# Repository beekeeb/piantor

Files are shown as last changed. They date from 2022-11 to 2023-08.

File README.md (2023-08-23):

# Piantor Keyboard

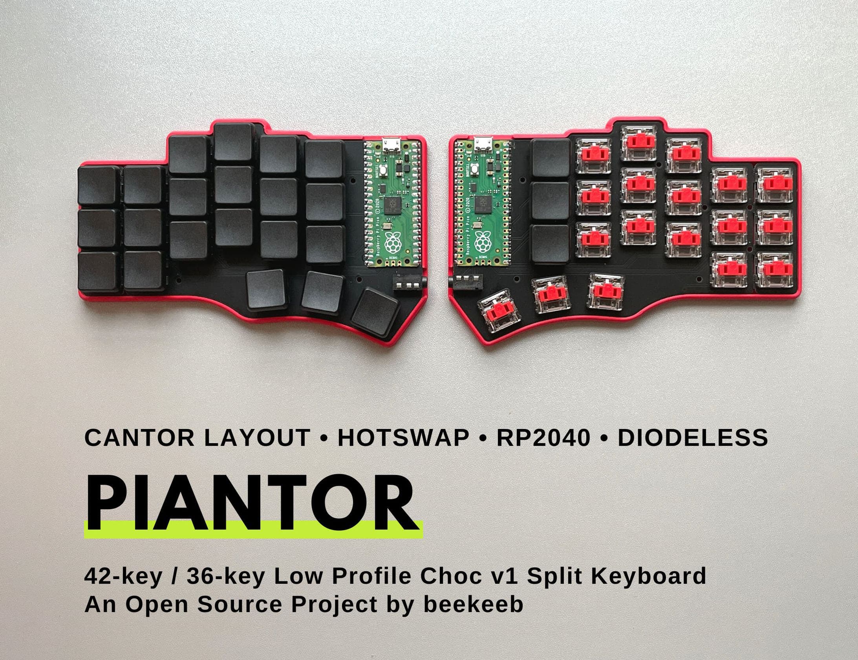
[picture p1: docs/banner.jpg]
Piantor Keyboard




The Piantor Keyboard is a 42-key or 36-key wired, diodeless, non-flippable, low profile choc v1 (hybrid hotswap and non-hotswap/soldered-in), aggressive column staggered, programmable ergonomic mechnical split keyboard powered by Rasyberry Pi Pico or other compatible RP2040 boards. It is based on the [Cantor Keyboard](https://github.com/diepala/cantor). The name "Piantor" is the portmanteau of "Pico" and "Cantor".

The development of this project is sponsored by [PCBWay](https://pcbway.com/g/beekeeb) (affiliate link).

## Quick Links

* [Build guide](https://docs.beekeeb.com/piantor-keyboard#build-guide)
* [Precompiled firmware](https://docs.beekeeb.com/piantor-keyboard#precompiled-firmware)
* [beekeeb showcase](https://showcase.beekeeb.com/piantor-keyboard/)

## Features

* RP2040 MCU - A low-cost, easy-to-source, powerful microcontroller with dual Arm Cortex-M0+ @ 133MHz, 264kB on-chip SRAM and 2MB (up to 16MB, depending on the breakout board) off-chip external flash memory. You can enable a lot of features and layers. Never worry about the firmware size limit.
* Cantor layout - Ergonomic strong column staggering for short pinkies.
* Non-flippable PCBs - Fewer ways to make mistakes when you install the controller breakout boards. Great for first time keyboard builders.
* Diodeless - A more robust build with fewer things to solder or break.
* Hybrid hotswap and soldered-in low profile choc switches - Experiment with different key switches with the hotswap sockets, or solder the key switches for a more stable build.
* Breakable pinky column - Easily convert the PCB from a 42-key to 36-key layout. You can snap off the pinky column without specialized tools.

## Bill of Materials (BOM)

Quantity | Item | Notes
--- | --- | ---
1 | Piantor PCB (Left)
1 | Piantor PCB (Right)
2 | RP2040 breakout boards (such as Raspberry Pi Pico or WeAct RP2040)
42 (or 36) | Kailh choc v1 PG1350 switches
42 (or 36) | "choc spacing" choc v1 keycaps
2 | TRRS jack (PJ-320A)
1 | 3.5mm TRRS cable | TRS cable cannot be used
42 (or 36) | CPG135001S30 hotswap sockets for choc v1 PG1350 | Optional, you can solder the switches directly if you do not use hotswap sockets
4 | Pin headers (20p) or sockets  | Only required for boards without castellated holes
2 | 10kΩ 1206 (3216M) SMD resistor | Only required if you do not want to use SPLIT_USB DETECT, and for boards without a built in VBUS_SENSE circuit
2 | 5.6kΩ 1206 (3216M) SMD resistor | Only required if you do not want to use SPLIT_USB DETECT, and for boards without a built in VBUS_SENSE circuit

* Note: Raspberry Pi Pico comes with castellated holes and a built in VBUS_SENSE circuit

## Ordering Parts

[DIY kits](https://shop.beekeeb.com/product/piantor-keyboard-kit/) and [prebuilt keyboards](https://shop.beekeeb.com/product/pre-soldered-piantor-split-keyboard/) are available at https://beekeeb.shop

If you prefer getting the parts by yourself, you can order the [Left Side PCB](https://www.pcbway.com/project/shareproject/Piantor_Keyboard_Left_side_24a2937f.html) and the [Right Side PCB](https://www.pcbway.com/project/shareproject/Piantor_Keyboard_Right_side_7c5b31eb.html).

A single side should cost around $31 for 5 pcs excluding shipping. For both sides, it should be around $62 in total for 5 sets.

## Firmware Status

* [QMK](https://github.com/qmk/qmk_firmware) - supported
* [Vial](https://github.com/beekeeb/vial-qmk-piantor) (based on QMK) - supported
* KMK (Python/CircuitPython) - pull request at https://github.com/KMKfw/kmk_firmware/pull/723
* [An example of KMK with miryoku](https://github.com/hansamann/piantor_miryoku_mac) by [hansamann](https://github.com/hansamann)
* Remap - support planned (No ETA)
* PRK (Ruby) - support planned (No ETA)
* keyberon (Rust) - support planned (No ETA)
* ZMK - waiting for [wired split support](https://github.com/zmkfirmware/zmk/issues/1110)

Precompiled firmware can be found at https://docs.beekeeb.com/piantor-keyboard.

## Cases

* [Piantor Gasket Mount Case by chewiedies](https://www.printables.com/model/536044-piantor-gasket-mount-case)
* [Piantor 36-key case with Tenting & Magnets! by Daave](https://www.printables.com/model/381730-piantor-36-key-case-with-tenting-magnets)
* [Travel case for Piantor keyboards by Rilton](https://www.printables.com/model/558902-travel-case-for-piantor-keyboards)

### Piantor Case with a Switch Plate (3D Printable)

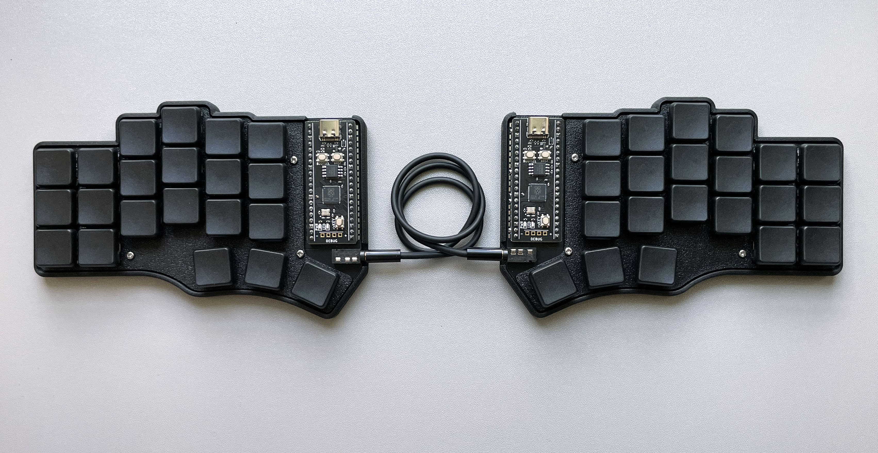
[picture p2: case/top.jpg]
Piantor Keyboard Case


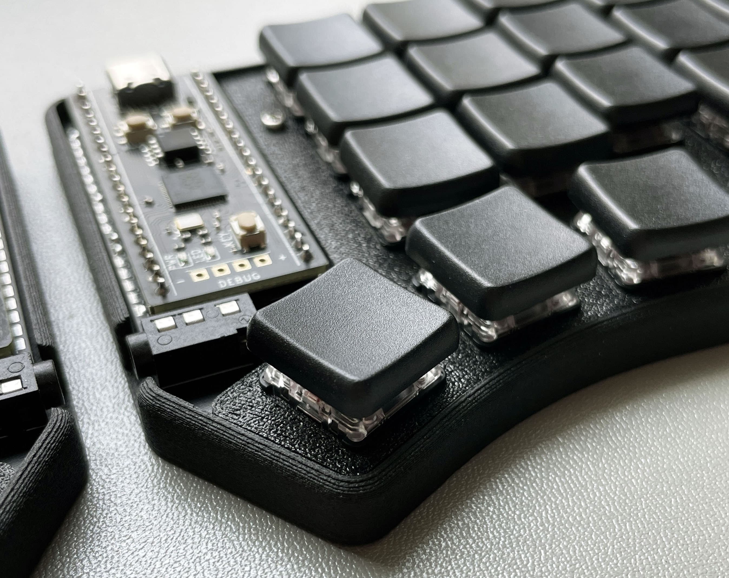
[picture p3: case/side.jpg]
Piantor Keyboard Case


The 3D printable case can be founded in the [case folder](./case). The switch plate is optional for the non-hotswap version.

GB823 M2 stainless steel screws with small pan heads are recommended.

* Screw Length
  * No switch plates: 4mm
  * With Switch plates: 6mm
  * With Switch plates and [Donut0804](https://shop.beekeeb.com/product/donut-silicone-rubber-feet-and-pads-o-rings-washers-like/)/o-rings: 7mm

Do not over-tighten the screws.

### Cantor Tray Case

The [Cantor Tray Case](https://www.thingiverse.com/thing:5382705) by chewiedies can be used. There is not a switch plate so it is not recommended for the hotswap version.

## Boards Preview

<p>
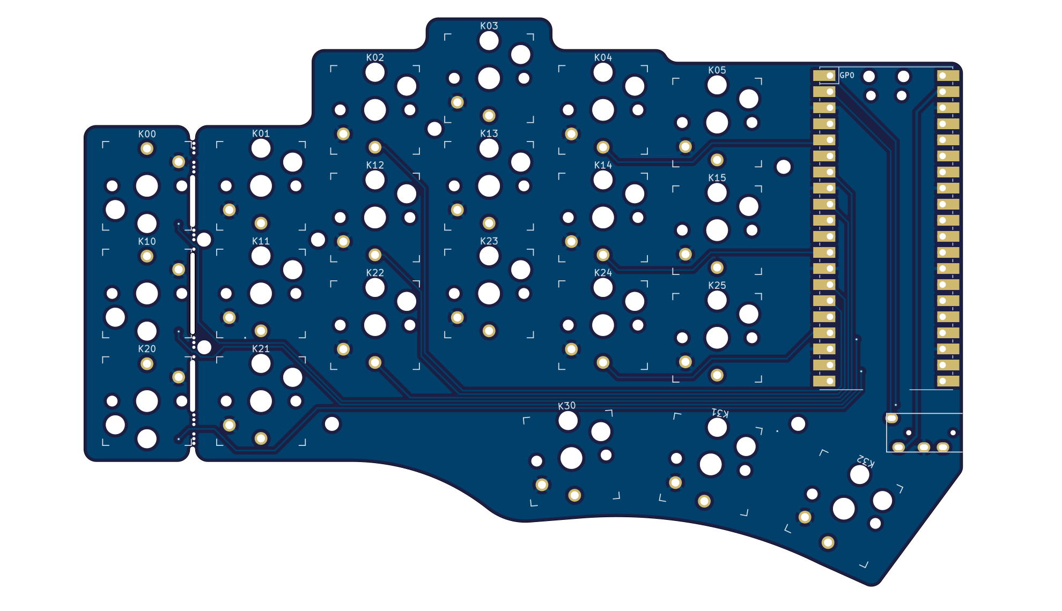
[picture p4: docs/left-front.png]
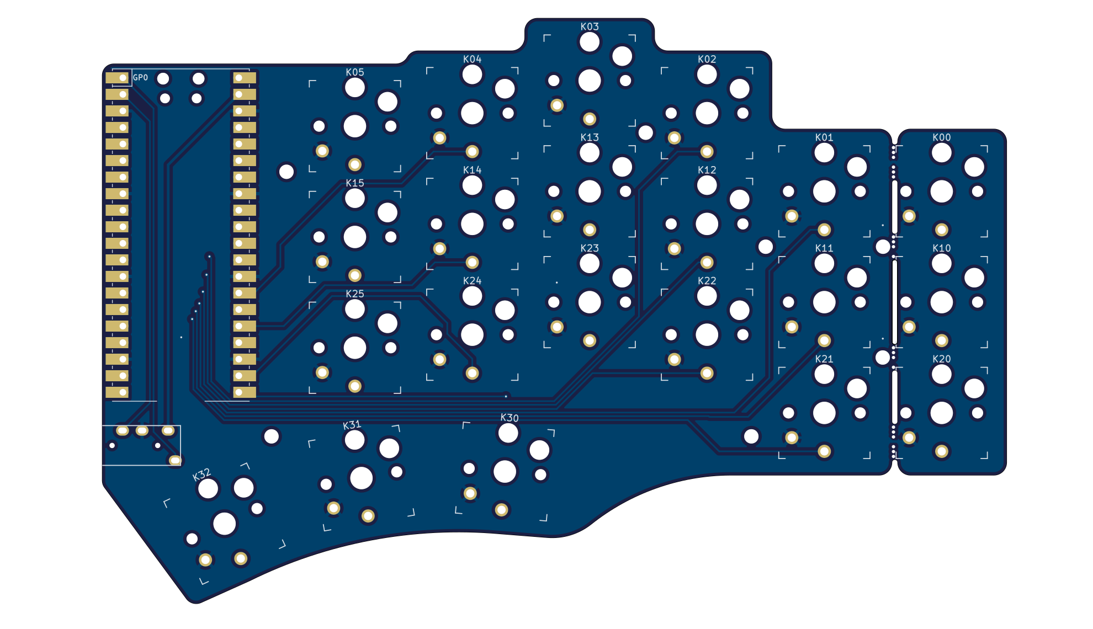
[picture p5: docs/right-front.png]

</p>
<p>
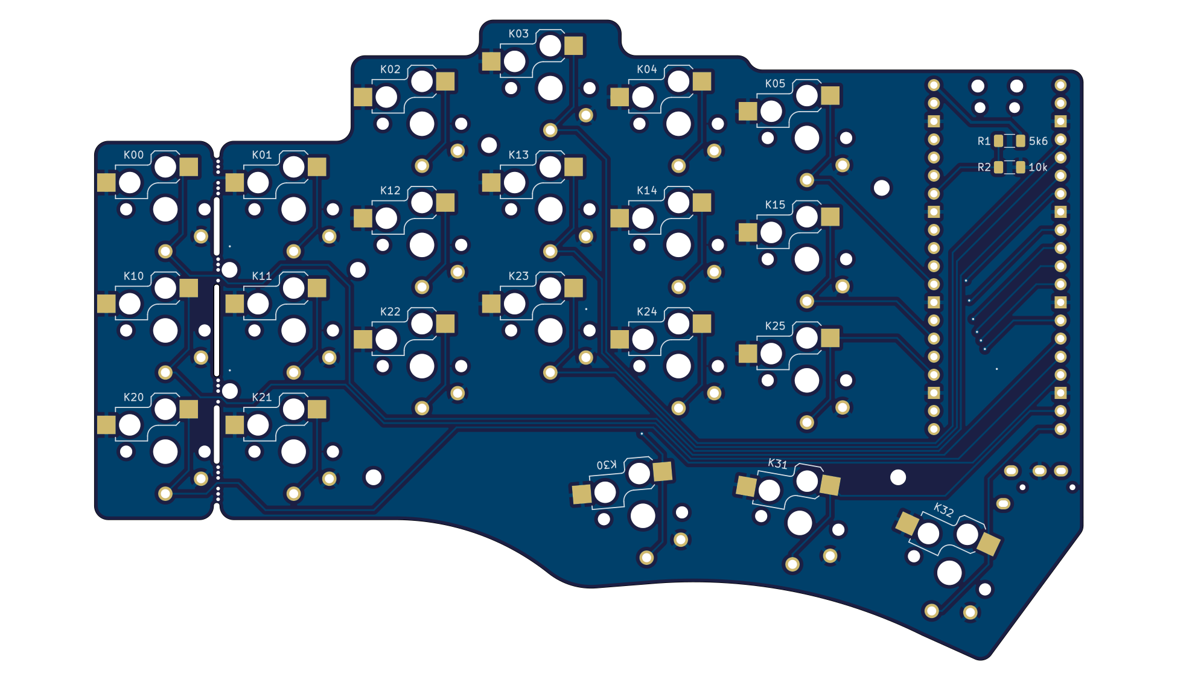
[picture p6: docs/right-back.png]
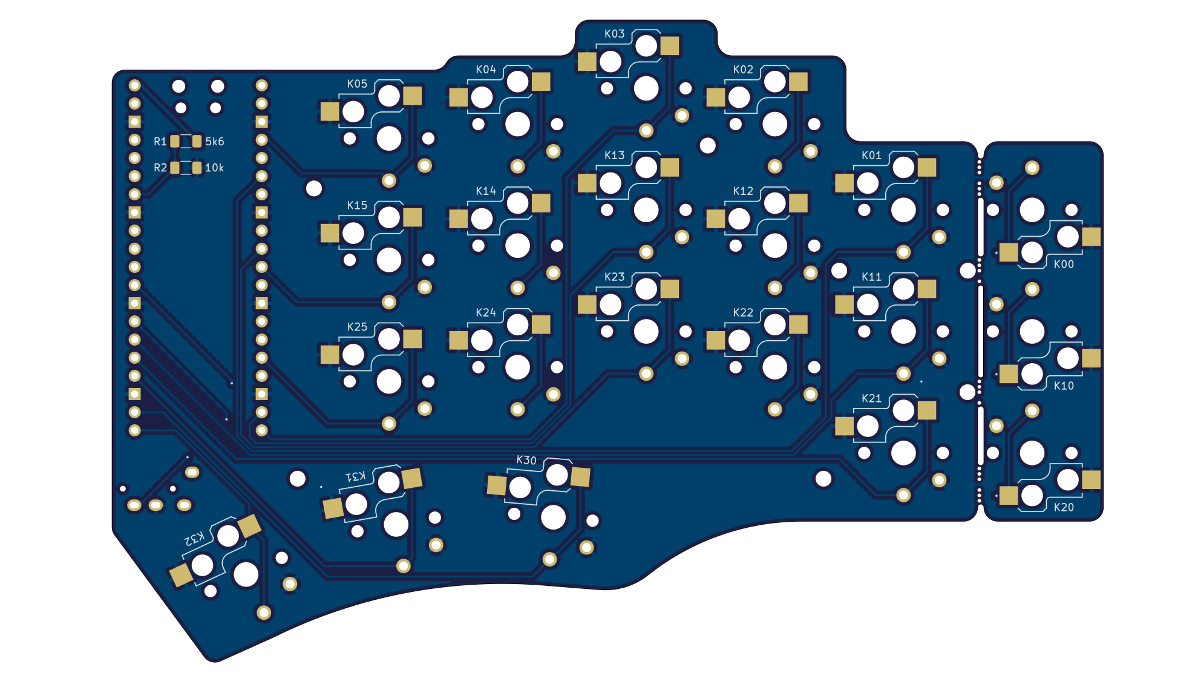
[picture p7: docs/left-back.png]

</p>

## License

External symbols and footprints are not covered by the LICENSE in this repo.

* [Keebio-Parts.pretty](https://github.com/keebio/Keebio-Parts.pretty) is licensed under the MIT License.
* [keyswitches.pretty](https://github.com/daprice/keyswitches.pretty) is licensed under the Creative Commons Attribution-ShareAlike 4.0 International License.
* [KiCad-RP-Pico](https://github.com/ncarandini/KiCad-RP-Pico) is licensed under the TPCWare KiCad Library License.
## Sponsors

This open source hardware project is sponsored by

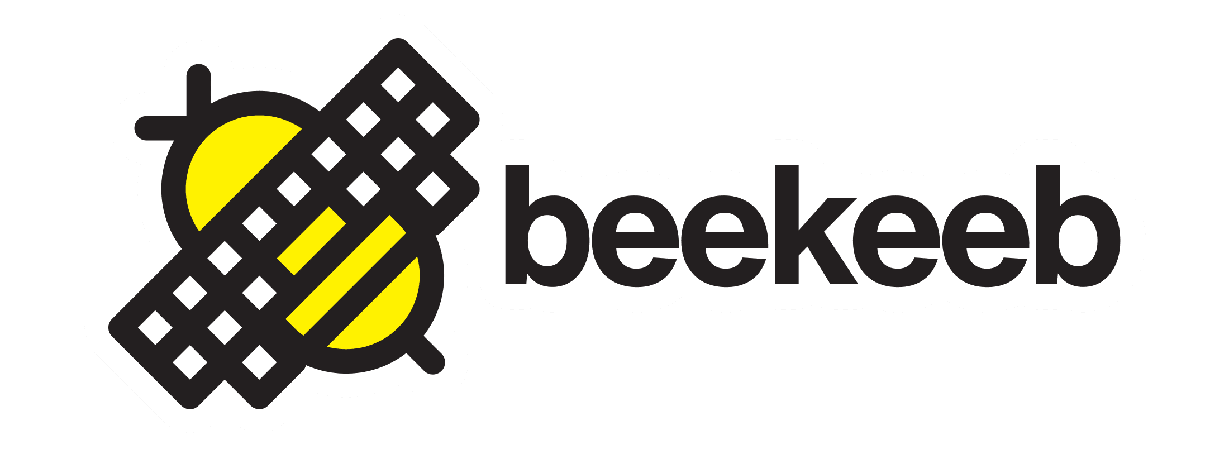
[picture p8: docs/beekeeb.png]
[](https://beekeeb.shop)
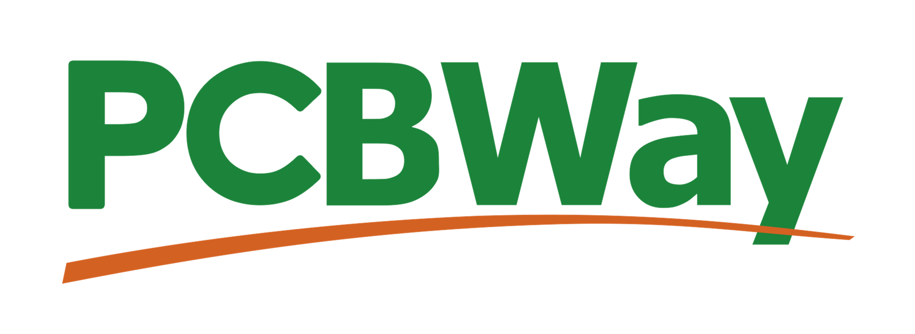
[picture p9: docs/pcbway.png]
[](https://pcbway.com/g/beekeeb)

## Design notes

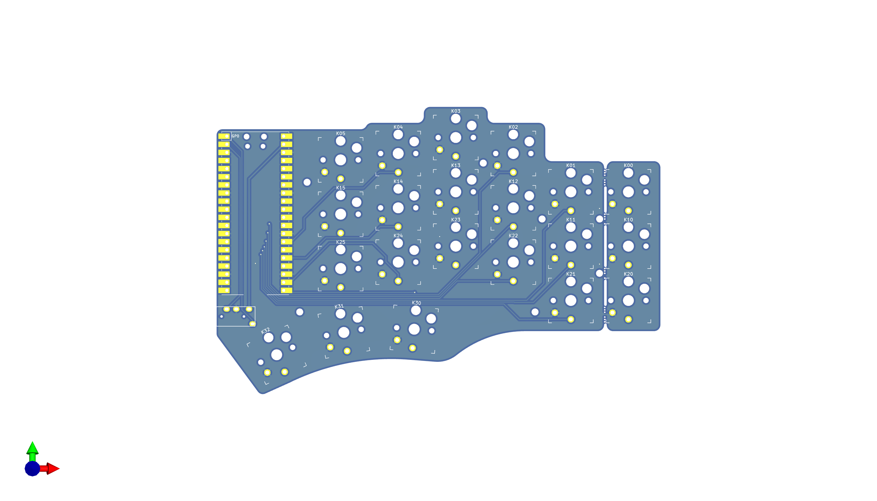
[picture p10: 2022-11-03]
docs/keyboard_right.png

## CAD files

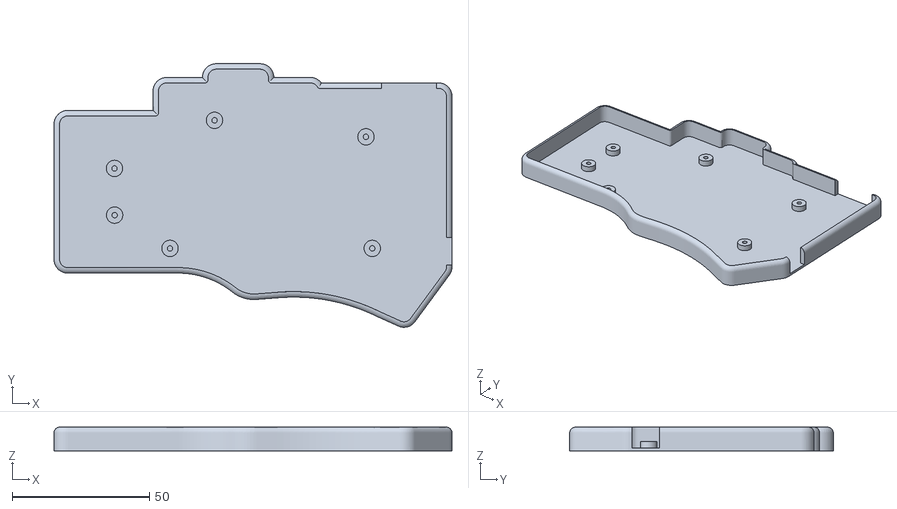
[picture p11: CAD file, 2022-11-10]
case/bottom.stl
144.8 x 95.9 x 8.60

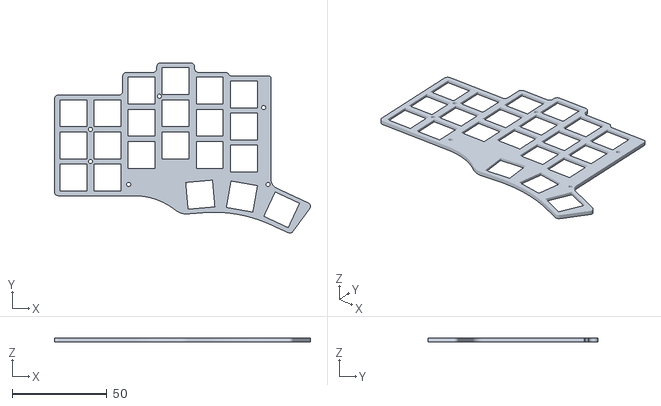
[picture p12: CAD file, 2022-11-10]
case/switch-plate.stl
135.2 x 89.9 x 2.00

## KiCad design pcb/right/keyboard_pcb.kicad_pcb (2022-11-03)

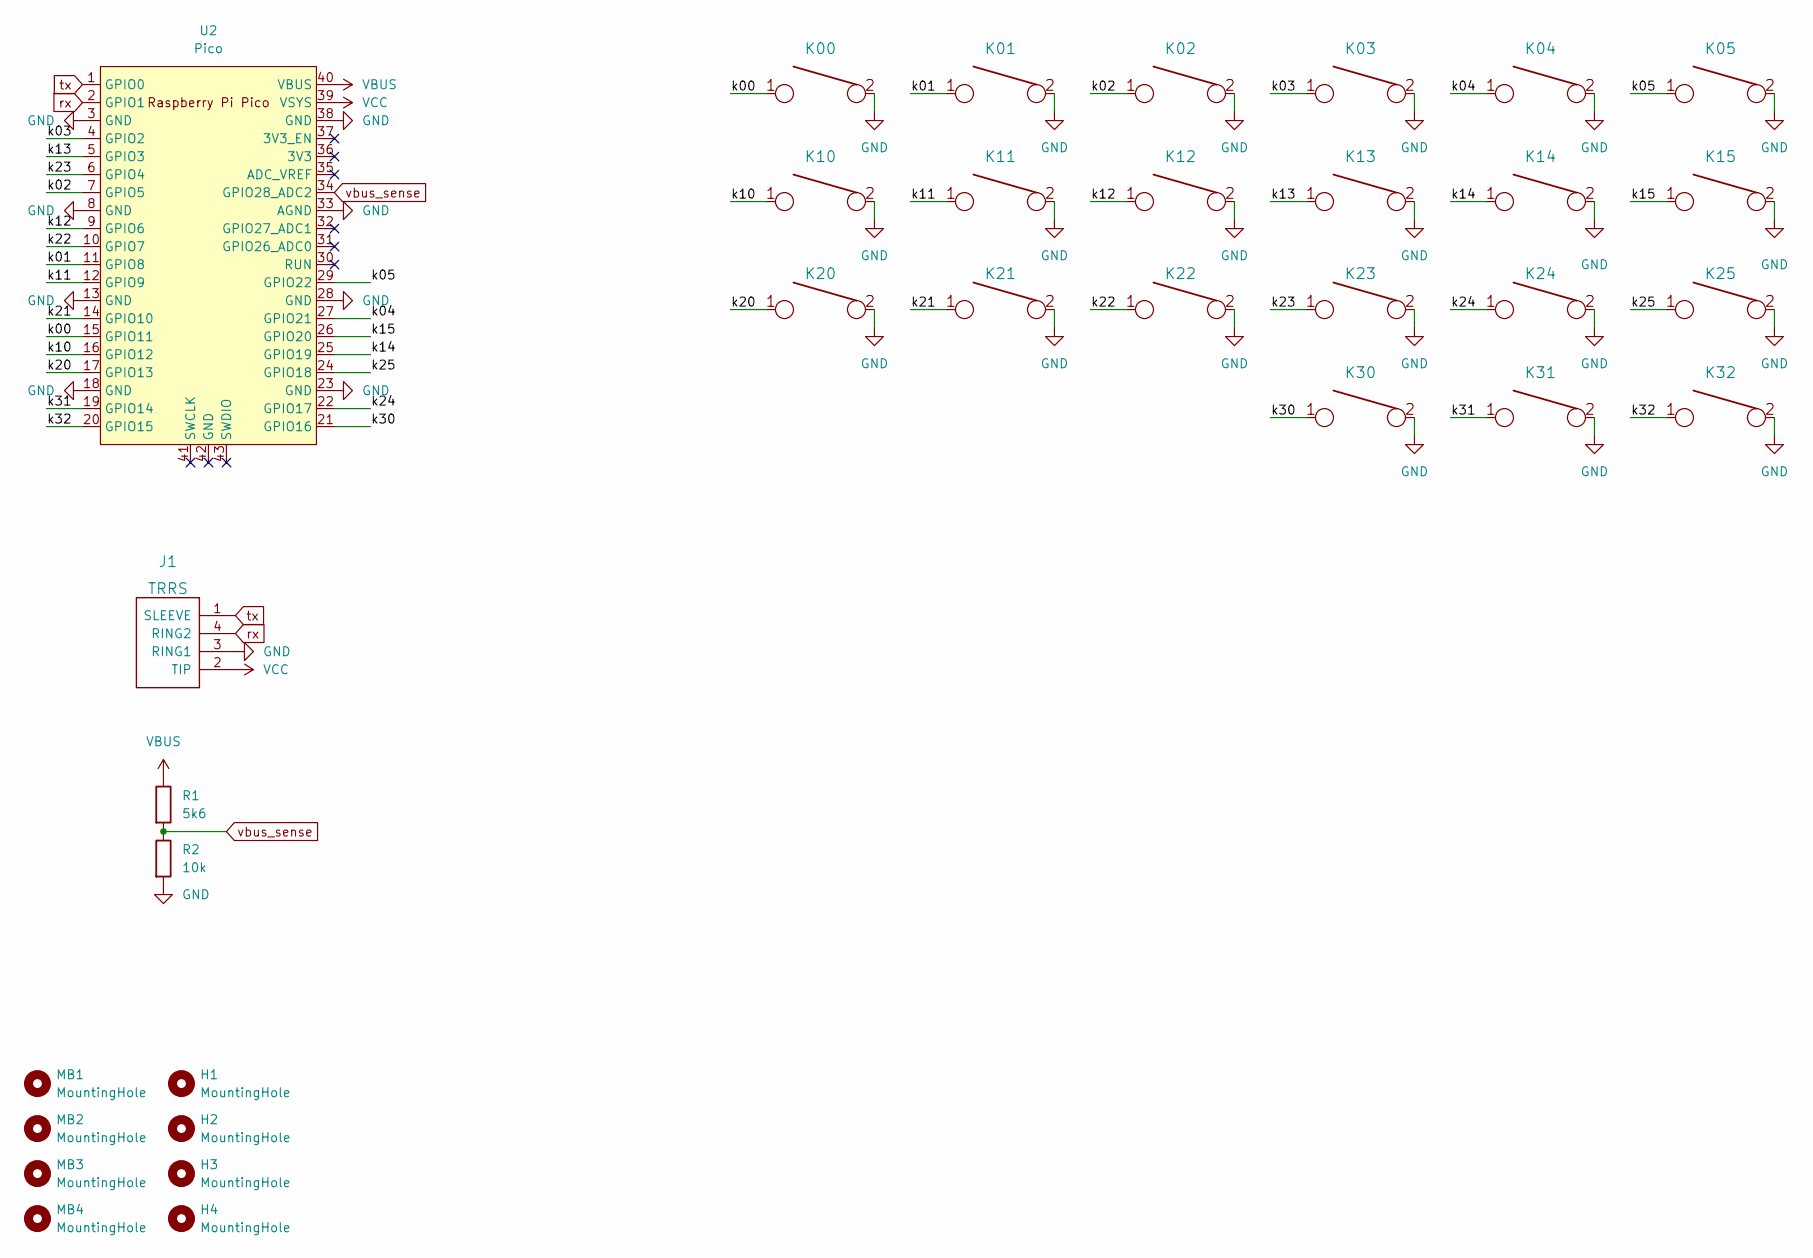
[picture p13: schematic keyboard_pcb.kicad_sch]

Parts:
H1, H2, H3, H4: MountingHole; MountingHole_2.2mm_M2-8mm
J1: TRRS; R_1206_3216Metric_Pad1.30x1.75mm_HandSolder
K00, K01, K02, K03, K04, K05, K10, K11, K12, K13, K14, K15, K20, K21, K22, K23, K24, K25, K30, K31, K32: KEYSW; SW_PG1350_reversible
MB1, MB2, MB3, MB4: MountingHole; mousebites
R1: 5k6; R_1206_3216Metric_Pad1.30x1.75mm_HandSolder
R2: 10k; R_1206_3216Metric_Pad1.30x1.75mm_HandSolder
U2: Pico; RPi_Pico_SMD_TH

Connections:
/k00: K00.1, U2.15 (GPIO11)
/k01: K01.1, U2.11 (GPIO8)
/k02: K02.1, U2.7 (GPIO5)
/k03: K03.1, U2.4 (GPIO2)
/k04: K04.1, U2.27 (GPIO21)
/k05: K05.1, U2.29 (GPIO22)
/k10: K10.1, U2.16 (GPIO12)
/k11: K11.1, U2.12 (GPIO9)
/k12: K12.1, U2.9 (GPIO6)
/k13: K13.1, U2.5 (GPIO3)
/k14: K14.1, U2.25 (GPIO19)
/k15: K15.1, U2.26 (GPIO20)
/k20: K20.1, U2.17 (GPIO13)
/k21: K21.1, U2.14 (GPIO10)
/k22: K22.1, U2.10 (GPIO7)
/k23: K23.1, U2.6 (GPIO4)
/k24: K24.1, U2.22 (GPIO17)
/k25: K25.1, U2.24 (GPIO18)
/k30: K30.1, U2.21 (GPIO16)
/k31: K31.1, U2.19 (GPIO14)
/k32: K32.1, U2.20 (GPIO15)
GND: J1.3 (RING1), K00.2, K01.2, K02.2, K03.2, K04.2, K05.2, K10.2, K11.2, K12.2, K13.2, K14.2, K15.2, K20.2, K21.2, K22.2, K23.2, K24.2, K25.2, K30.2, K31.2, K32.2, R2.2, U2.3 (GND), U2.8 (GND), U2.13 (GND), U2.18 (GND), U2.23 (GND), U2.28 (GND), U2.33 (AGND), U2.38 (GND)
VBUS: R1.1, U2.40 (VBUS)
VCC: J1.2 (TIP), U2.39 (VSYS)
rx: J1.4 (RING2), U2.2 (GPIO1)
tx: J1.1 (SLEEVE), U2.1 (GPIO0)
vbus_sense: R1.2, R2.1, U2.34 (GPIO28_ADC2)

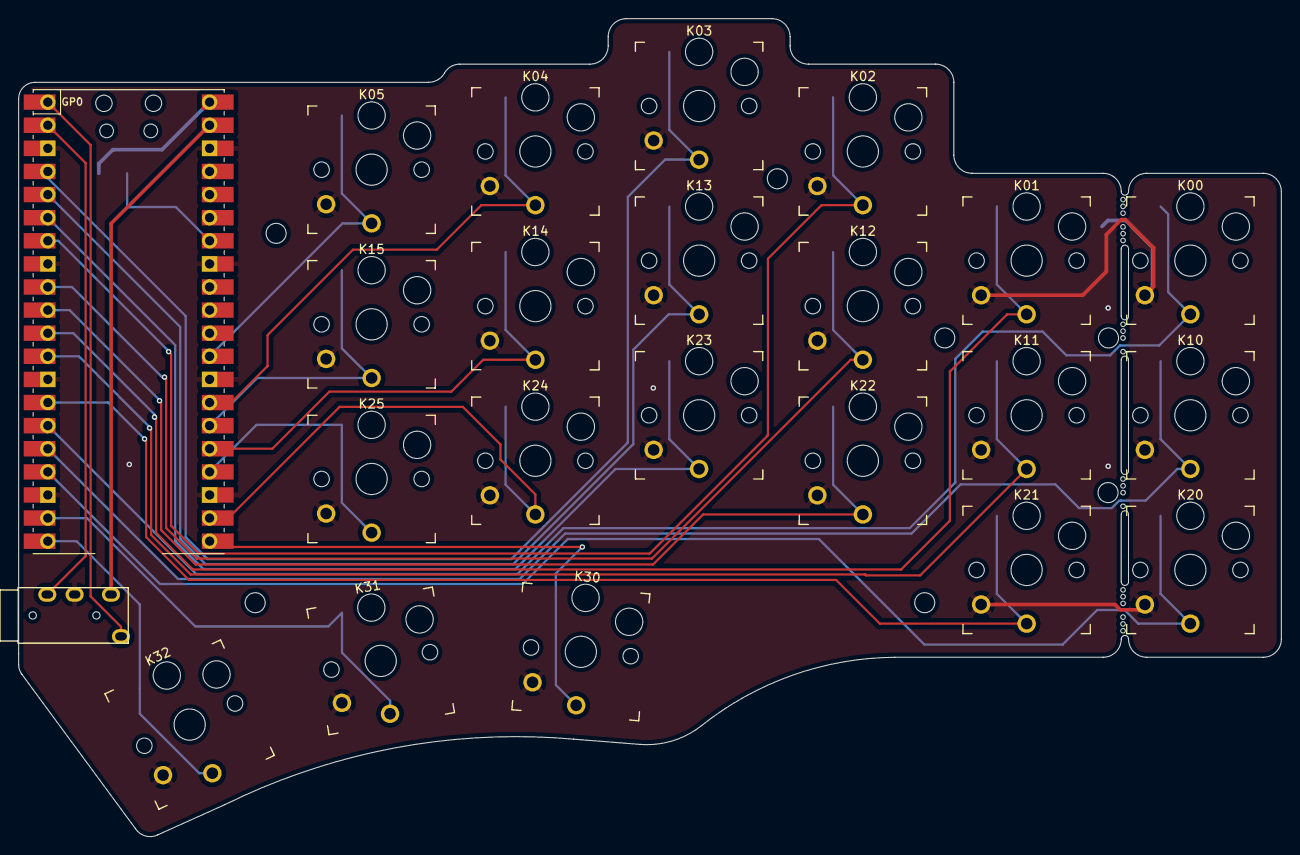
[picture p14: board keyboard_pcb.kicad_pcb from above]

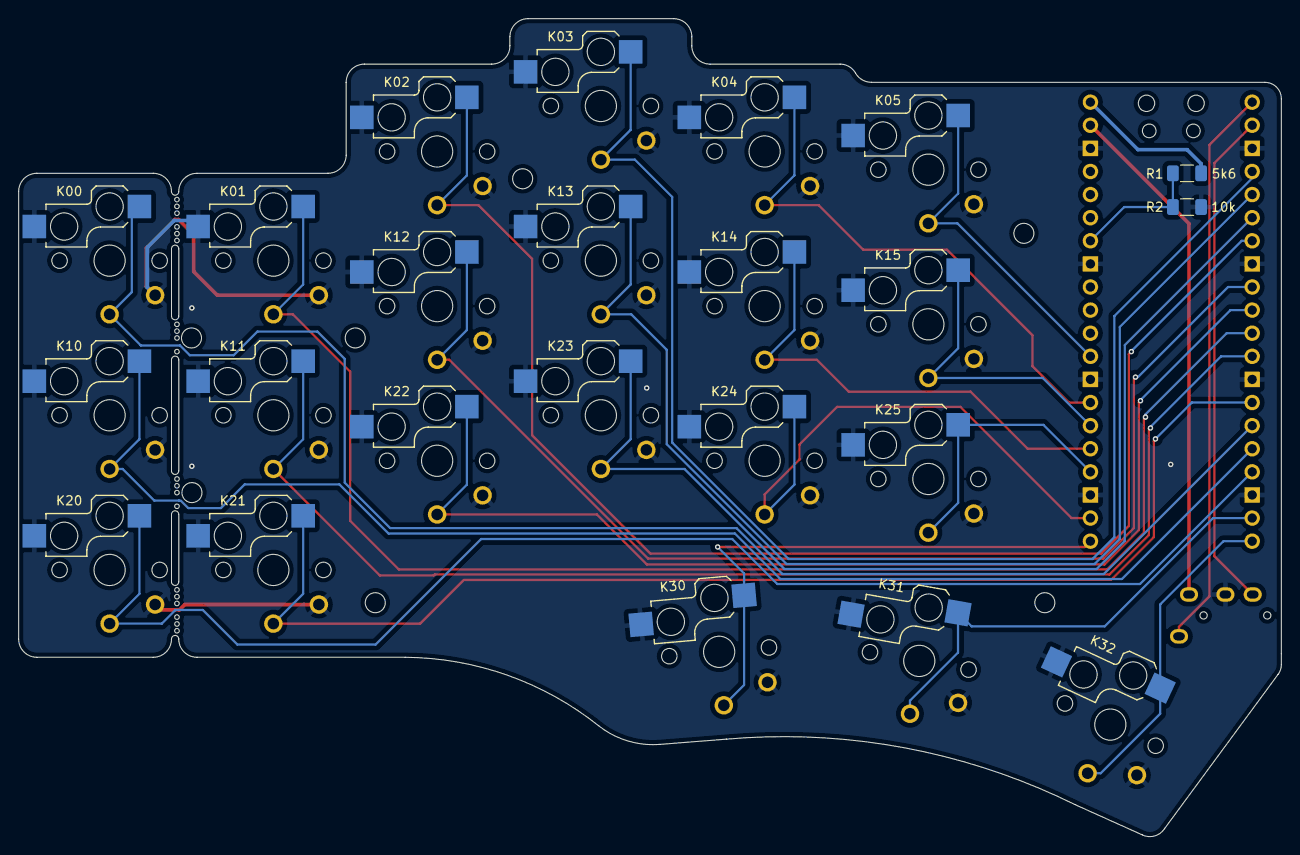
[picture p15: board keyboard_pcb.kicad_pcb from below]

Board: 2 copper layers, 138.8 x 89.9 mm, 36 parts (13 on the bottom side), 27 nets.

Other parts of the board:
H1#2, H4#2, H4#3: MountingHole; MountingHole_2.2mm_M2-8mm

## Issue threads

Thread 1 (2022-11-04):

Only USB-C ports

Lumi571, 2022-11-04:
Would it be possible to create a version of the Piantor whose TRRS ports are replaced by USB-C ports?

l4u, 2022-11-04:
Thank you for the suggestion, Lùmi! To keep this beginner-friendly for hand soldering, the TRRS ports will not be replaced by USB Type-C ports. It might happen if there will be a PCBA version. You might be interested in https://github.com/KarlK90/yaemk-split-kb

Lumi571, 2022-11-04:
Thanks for taking time to respond to me. :)

It seems to me that I have read that complicated soldering, such as that of the USB-C ports, can be carried out by machines in the factory if a PCBA file is provided. In this case, why not use it to take advantage of the qualities of a USB-C port while saving yourself the task of soldering it?

PS: The Yaemk-split-kb unfortunately lacks shock spacing and strong column stagger.

l4u, 2022-11-05:
You can apply the schematic from yaemk-split-kb to this project to build your own version.

Closed 2022-11-05.

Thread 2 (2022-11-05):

Support MX hotswap sockets and key switches

torytang, 2022-11-05:

dcai, 2022-12-08:
Hi @torytang thanks for making piantor open source, will mx support be added anytime soon?

torytang, 2022-12-10:
Hi @dcai, we are working on it. But there isn't an ETA yet. Please subscribe to this issue for updates.

dcai, 2022-12-10:
@torytang thanks! Looking forward to it

albertothedev, 2023-04-11:
Any updates?

faboulaws, 2024-06-26:
There is Cantox mx version. Any plan of creating an Piantor MX? That would be awesome.

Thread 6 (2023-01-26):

Support bluetooth through Pico-BLE ?

zonetw, 2023-01-26:
I saw a module that can extend Pico to use Pico.
https://detail.tmall.com/item_o.htm?id=696942327882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

Not sure if this would work with the offical firmware?

l4u, 2023-01-28:
https://www.waveshare.com/wiki/Pico-BLE
I'm not aware of firmwares supporting the Pico-BLE. KMK with modifications might work. It seems to be designed as a wired bluetooth host instead of a battery-powered device.

There're other issues such as battery charging and power usage, comparing to the existing nrf52 solutions.

Closed 2023-01-28.

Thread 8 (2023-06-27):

Not an issue - Keycap stl file request

viyoriya, 2023-06-27:
Hi is it possible for you to share/add the stl file of keycaps  ?

(Keycap Set for Kailh Choc Switch PG1350 Low Profile (3D Printed with Nylon)I

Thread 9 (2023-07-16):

Case and Plate STEP files

adamcope, 2023-07-16:
Is there anyway we can get the step files for the two case .stl files? Importing the mesh into FreeCAD or Fusion 360 to make modifications to the case is a bit unwieldy.

sebkouba, 2023-12-23:
I would love that as well. I just realised the stl files need to be mirrored for the second side, right? The stl is just the right for the switch plate from what I can tell.

penk, 2024-02-24:
Even though not original, but I have recreated the case and the plate from KiCad PCB edge cut,
https://www.printables.com/model/771660-piantor-keyboard-36-42-key-case-and-pcb-plate

STEP file and DXF outline included. Hope that helps! :-)

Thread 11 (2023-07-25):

Keycaps size

arunoruto, 2023-07-25:
It would be nice to provide some information on the maximum size the keycaps can have without interfering with each other. I just got myself [these](https://splitkb.com/products/kailh-choc-transparent-keycaps?variant=31721735389261) transparent keycaps which are `17.5mm x 18mm`, while [normal MKB Keycaps](https://splitkb.com/collections/switches-and-keycaps/products/coloured-blank-mbk-choc-low-profile-keycaps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) are `17.5mm x 16.5mm`. I either have to buy new ones or shave off a few mm of the height to make them fit (since I like the transparent esthetic).

l4u, 2023-07-27:
Similar to Cantor, Piantor uses "choc spacing". The transparent keycaps are not compatible.

Closed 2023-07-27.

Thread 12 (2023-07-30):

Disconnecting the TPRS cable when the keyboard is plugged in fries the chip

SadraMoh, 2023-07-30:
Unfortunately I found this out the hard way when I was building my own keyboard using the DIY kit from beekeeb.

Now I know there are already warnings in the beekeeb docs warning against this, but it is inevitable that at some point this will happen by mistake. I acknowledge that it is mostly my fault this has happened and have no intention to blame the designers.

I would rather ask, is there a way to make this safer so this doesn't happen again to other people?

viyoriya, 2023-08-01:
If you design PCB place the routing of vcc/3v3 as last pin in TRRS then this wont happen

philong, 2023-08-15:
I've read that TRRS tip should be VCC and last ring should be ground. That way, you don't hit current until fully inserted, and shorting ground to VCC should be nearly impossible.

I wonder whether the Cantor is also affected.

jojo599k, 2023-08-19:
The cantor has following configuration:

- TIP (2) GND
- RING1 (3) RX
- RING2 (4) TX
- SLEEVE (1) VCC

The left and right piantor have the following configuration:

- TIP (2) VCC
- RING1 (3) GND
- RING2 (4) TX
- SLEEVE (1) RX

According to this comment on reddit https://www.reddit.com/r/MechanicalKeyboards/comments/b1s7c9/comment/einz0xw the configuration should be the following:

- TIP (2) VCC
- RING1 (3) TX / RX
- RING2 (4) RX / TX
- SLEEVE (1) GND

which is the reverse for GND and VCC for cantor configuration. That is also the configuration @philong is recommending.

I'm not quite sure what @viyoriya configuration would look like.

According to ChatGPT, the default configuration for transmitting data with a TRRS connector would be:

- TIP (2): RX (Receive Data)
- RING1 (3): TX (Transmit Data)
- RING2 (4): GND (Ground)
- SLEEVE (1): VCC (Voltage/Power Supply)

Which is the reverse of the piantor configuration.

I have sadly no experience with PCB design and wiring, so i cant give the right answer here. It would be nice if someone could clarify this. And of course if someone could update the pcb and create a PR.

viyoriya, 2023-08-22:
@jojo599k I used

    TIP (2) GND
    RING1 (3) RX
    RING2 (4) TX
    SLEEVE (1) VCC

same as cantor attached the pcb and sch diagram
 [](url)
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

hxse, 2023-08-31:
Really important hope that this problem can be solved.

pcky, 2024-02-14:
As a workaround i integrated an USB-C Socket as replacement into the 3D-printed case of my Piantor keyboard:
https://www.printables.com/model/764951

renanqts, 2024-04-15:
@pcky could you please let me know how you soldered this usb socket behind it?

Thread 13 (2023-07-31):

right side not working?

alifemove, 2023-07-31:
Any debug ideas?
The left side works just fine, and if I plug in the right side to the pc the key presses show up, but the opposite side never works. I've used two different cables to connect the two together and desoldered the TRRS Jacks and put different ones on as well.

alifemove, 2023-08-01:
```
check continuity on TX with right side RX (as well as RX with right side TX)
```
Not sure what that means, but I was able to use the firmware with right side master and the right side worked fine, and firmware with left side master and the left side worked just fine it just can't communicated between the two sides.

Im using the picos that came with the kit and the firmware from beekeeb.

viyoriya, 2023-08-01:
are you using qmk or kmk ?

If you have multimeter

      1. check continuity with Left side pico GP0 pin with Right side GP1  (TX => RX)
      2. check continuity with Left side pico GP1 pin with Right side GP0  (RX => TX)

      3. check TRRS each pin continuity
               1. vcc to vcc
               2. gnd to gnd
               3. TX to RX
               4. RX to RX

     check are you using TRRS (should have 3 black or white plastics in the plug ) or TRS

alifemove, 2023-08-01:
```
are you using qmk or kmk ?
```
I am using the firmware that comes from the docs from beekeeb so whatever that is.

```
If you have multimeter
```
I do not, but Ive used 2 different TRRS cables and jacks and both had the same issue. Seems like the issue is in the board to me.

viyoriya, 2023-08-01:
when its connected with TRRS right side is On or Off ?
is the Pico green or black ?

I guess maybe TRRS connection  or TRRS cable

alifemove, 2023-08-01:
```
when its connected with TRRS right side is On or Off ?
```
when left side is plugged in right side is off, when right side is plugged in left side is off.
```
is the Pico green or black ?
```
green
```
I guess maybe TRRS connection or TRRS cable
```
I desoldered and resoldered with new jacks and tried a different cable, neither helped.

viyoriya, 2023-08-01:
try re flashing  the firmware on both side

https://docs.beekeeb.com/piantor-keyboard#precompiled-firmware

or you can compile your own firmware

for KMK -     https://github.com/KMKfw/kmk_firmware/pull/723/files
for QMK -    https://github.com/qmk/qmk_firmware/tree/master/keyboards/beekeeb/piantor

flash tool for linux  - https://github.com/raspberrypi/picotool
for windows just copy uf2 file in bootloader mode

(if find multi meter
   1, check voltage 3v3 out pin with any gnd pin - right side 5th pin)
    2. TX / RX pins )

mbetim, 2023-09-15:
@alifemove can you share how you solved this issue?

I have a similar one, but I have the WeAct RP2040, and the side that isn't directly connected to the computer light up, so both halves have power.

Here's what I've tried so far:
* Reflashing (even using the firmware to clear the flash)
* Resoldered some joints, especially the ones for the TRRS cable
* Checked the pins mentioned by @viyoriya with the multimeter, and everything seems to be fine
* Flashed the firmware that turns the right side as the master one
* Tried the keyboard on a different computer
* Built and flashed a firmware with qmk configurator

To give more context as well, the keyboard was working before. This started happening after I've (mistakenly) disconnected the TRRS cable before unplugging the USB and resoldered a socket joint that wasn't good. One event happened after the other, so I don't know which one could've caused it.

alifemove, 2023-09-15:
@mbetim I didn't solve it. But it's a known issue that if you unplug the TRRS cable while its powered it will short out so I'd say that was it. I've spoken with Leo and he's working on a version that doesn't do that.

danjessen, 2023-12-24:
I have this same issue. Nothing worked. Both controllers still seem to react when plugged individually. But the connection between them seems broken.

ChristianHinge, 2024-02-20:
I seem to have fixed the issue by resoldering the GP0->GP1 connections.

danjessen, 2024-02-20:
I used a different controller that was a supposed clone of the pi. But turns out there are some differences. And I need to solder a bride.

Closed 2023-08-11.

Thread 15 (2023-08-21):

question about flash the borad, which flash file?

sIHURs, 2023-08-21:
I would like to ask a question about the file "beekeeb_piantor_rpi_pico_vial.uf2." Should this file be loaded into both the left and right microcontrollers (raspberry pi pico)? After loading, my right-hand device actually has the layout of the left hand?

sIHURs, 2023-08-21:
and only the keyboard connected to the USB side is working properly, while the other half shows no response when plugged in.

AlexeyKhrenov, 2023-10-06:
I guess, you already figure out the answer :) anyway, for newcomers:
you need to put .uf2 on 2 parts separately while they're not connected with a cable. Now you can join them together and to PC. The side connected to the PC becomes master.

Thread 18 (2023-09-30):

QMK RP2040 and RGB

markkimsal, 2023-09-30:
i've been trying to read the source and readmes, but i can't tell if there are any default pins configured for the RP2040 that deal RGB.  I really could like just a few addressable RGBs to tell what layer i'm on as I often get stuck toggled on weird layers that I wasn't expecting.

Is it simply not possible to add rgbs to this board?

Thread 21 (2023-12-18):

Piantor stopped working

VinciTec, 2023-12-18:
Anyone have an idea what is wrong?

I have happily used a Piantor keyboard for a couple of months now, and regularly take it with me to other places in a protective bag from Beekeeb. Now I plugged it in again and is seems to have stopped working correctly.

First of all, I'm aware unplugging the TPRS cable whilst powered can cause components on the microcontrollers to be damaged, so I have been very careful each time when packing away the keyboard. As far as I am aware I have never unplugged the TPRS cable before unplugging the USB C cable. However, as there seems to be no other change from the last time the Piantor still worked, maybe this happened without me realizing. Although, I don't believe I did.

Anyway, when connecting power to the (normal left-side of the) keyboard now the power LEDs glow much weaker than before, and fluctuate slightly. Connected this way, my computer receives no signals form the keyboard when keys are pressed. However, very infrequently a couple of key presses go through (the LED seems to also glow brighter when this happens).
The weird thing, to me at least, it that when I connect the USB C to the right side of the Piantor, both LEDs glow as normal and all key presses register fine. However, when plugged in on this side the key mapping is all wrong as the QMK config of the Piantor is configured relative to the left side.
Moreover, when just using the left half of the Piantor (meaning I connect the USB C to the left side without using the TPRS cable to connect to the right side) the LED glows at normal brightness and all key presses register correctly. But in this setup I am not able to use the right side, so I cannot use the keyboard in this way.
By the way, I can still upload new firmware without any problems.

It seems I could use the keyboard by connect to the right side and reconfiguring the keymapping. However, clearly something is wrong, and I do not want to damage the micro controller further.

Does anyone have an idea what is wrong with my Piantor? What could have caused it? Might it be a firmware problem that can easily be resolved? Or can I replace a component?
Thanks for any help.

VinciTec, 2023-12-28:
I imagine the problem must lie with (one of or both) the microcontrollers. Is there any way I can troubleshoot this? Test which one is broken so I can possibly replace it?

quirq, 2024-02-07:
I've had the same issue a number of months after I got my keyboard - but I received the v2 with USB-C on both halves.

I have tried to reflash the firmware on the RP2040, but it loses it after unplugging the keyboard.

Expect that the issue is with the RP2040 or the board in general, but haven't figured it out yet.

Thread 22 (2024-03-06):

One side of the keyboard not working

Hentuloo, 2024-03-06:
Hi, I encountered a problem where only one part of the keyboard was working after assembly, depending on the connected power source, as shown in the picture where the LED only lights up on one side:

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

I'm using Tzt raspberry pi pico board rp2040 16MB (dual-core 264kb arm low-power mikro computer hoch leistungs Cortex-M0 + prozessor) which was purchased on AliExpress.

While searching for a solution, I came across a diagram:

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

It appears that the Vin and Vout pins are connected/shorted, whereas on my boards they were not connected. After soldering these pins on both parts, the keyboard started functioning 🎉

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

The problem lies in the fact that the second board had insufficient voltage, which prevented it from starting up.

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

I have created this issue requesting to add some information about it on the BeeKeeb homepage. It may help people like me who have bought similar microcontrollers.

magicalpuffin, 2024-03-07:
This is a really great find. I bought a Aitexm Raspberry Pi Pico Board RP2040 TYPE-C 16 MB on Aliexpress and I was having similar issues where I could only get one half connected.

I tried soldering the Vin and Vout pins and was able to get both LEDs to light up, however, I couldn't get the Vial firmware to work.

I already permanently damaged one microcontroller when I tried to remove it so I'll have to abandon my build but this does have potential to help others.

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

Hentuloo, 2024-03-07:
I also had other issues with the keypads that I didn't mention:

1. one of the keypads refuses to connect to the computer at all; it shows a message that the device is unknown. I tried various things, but it's likely that it needs to be replaced (I recommend ordering a spare from AliExpress right away).

2.  I also encountered problems with the remaining keypads. Initially, I used the beekeeb_piantor_rpi_pico_vial.uf2 software available on the beekeeb website (https://docs.beekeeb.com/piantor-keyboard#firmware-for-clearing-the-flash)

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

but the keyboard didn't appear in the Vial software. In the web version (https://vial.rocks/) I noticed the console error "device read timed out!" (screen)

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

After several attempts, I decided to install the beekeeb_piantor_vial.uf2 software, which is the third option from the top, and both Vial web and desktop versions **started working**.

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

Before flashing any software, I cleared the memory using flash_clear.uf2 "Firmware for clearing the flash," which is also available on beekeeb (https://docs.beekeeb.com/piantor-keyboard#firmware-for-clearing-the-flash).

mumblingdrunkard, 2024-03-21:
Just adding this for anyone searching for "YD-RP2040 Piantor".
My friend bought YD-RP2040 controllers and this same "hack" works on this.
Shorting Vin and Vout on the master side lets the other side receive power.

This happens because the original Pico has Vbus and Vsys instead of Vout and Vin, respectively.  Vsys can source current and the Piantor PCB has a trace running from Vsys to the TRRS port and uses that to power the non-master side.
On the YD-RP2040 (and whatever the controllers here are) this pin is replaced with Vin, which cannot source current, and delivers no power to the TRRS port, although it can receive power from it.

This is/should be safe as you're only bypassing the diode that goes from Vin to Vout, but experiment with your cheap knockoff microcontrollers at your own risk.
I _believe_ it's safe to short both sides provided you only power one side at a time, but you only need the short on the master side.

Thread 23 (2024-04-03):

Contribution Access

lecrouch, 2024-04-03:
Hello,
I had some major struggles with getting a [YD-RP2040](https://circuitpython.org/board/vcc_gnd_yd_rp2040/) to work on the PCB and have a PR ready to go that add notes to the `README.md` explaining how to make the YD-RP2040 work on the Piantor.

If you don't want to give me access to open a PR, I can paste the notes I have here for you (in the BOM table)

Thanks!

extua, 2024-06-08:
In case these issues are connected, is this the same problem with the YD-RP2040 mentioned in https://github.com/beekeeb/piantor/issues/22#issuecomment-2012335168 ?

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

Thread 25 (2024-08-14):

Pico built-in led

serhiimakarov, 2024-08-14:
Is there possibility to use built-in led of pico to show current layer?

For example:

left off + right off -> 0 layer
left off + right on -> 1 layer
left on + right off -> 2 layer
left on + right on -> 3 layer
...

If go further, we also can use blinking led and continue list of layers

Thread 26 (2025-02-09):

limit of the power led

Gabriele-tomai00, 2025-02-09:
hello, beautiful project. I have a doubt about the LEDs. I see you used leds that draw up to 60mA. The raspberry pi pico can handle 500mA maximum. How does that work? Did you reduce the brightness a lot?

Thanks

Closed 2025-02-09.

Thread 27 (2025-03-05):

Right side not working (sometimes and partially)

sollted, 2025-03-05:
I love the keyboard but sometimes right half (slave) stops working, the led is still on but input doesn't work for some time from seconds to minutes it can even stop working completely.
When this happens i disconnect keyboard and reconnect or press the reset button but mostly waiting is enough.
It is extremely irritating. I switched from bluetooth corn keyboard exactly because issues like this one.

For replicating:

- flashing .uf2 to left half (disconnecting then holding BOOTSFL while connecting.
- I am getting firmware from QMK configurator. in safari but tried chrome (it should not have any effect)
- Mac m1 pro this issue persisted throughout all versions of OS
- Czech keyboard layout (if it matters)

Thanks for response in advance.

mertoldi, 2025-05-10:
I'm encountering exactly the same problem, this has only started happening recently, nothing has changed on the computer.  The keyboard is used on a windows 11 machine.

sollted, 2025-05-15:
I made the problem more manageable by increasing timeout in QMK configuration. (this didn't fix it but made it occur less often). But I resoldered the keyboard (for 3rd time) and now it works.

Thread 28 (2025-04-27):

Piantor Right Half (slave) Not Working

Heinrich-XIAO, 2025-04-27:
It was working fine until it randomly stopped working. I feel like it has to be a hardware issue since software is generally predictable. I notice that when the issue was first happening, it would register one or two keys at the start and then stop. It is no longer doing so, either because I haven't done thing that would replicate it or it truly stopped. I've checked the TRRS cable connecting them and there are no shorts and everything connects correctly within the cable. After that, I checked if the pins that are supposed to connect for the TRRS cable were connected, and indeed they were. The left side is a WeAct that came with the keyboard and the right side (slave and not working) is a RPI Pico (not 2). Plugging in the right side on its own works fine except the keys are different which is expected.

Firmware: QMK then tried Vial and it still didn't work.

What should I try next?

mertoldi, 2025-05-10:
I have the same problem , on windows 11 with 2 raspberry pi pico's

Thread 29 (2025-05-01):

ZMK Support

dani0854, 2025-05-01:
Experimental ZMK wired split support was added recently:
https://github.com/zmkfirmware/zmk/issues/1110

Disclaimer, I am not an expert in ZMK or any type of embedded development in general.

I managed to get my piantor keyboard working with ZMK.
And created a ZMK module for it (as I understand the direction of ZMK currently is to move shield/board support to modules, instead of defining them in-tree), could be useful to someone.
https://github.com/dani0854/zmk-keyboard-piantor

Some things are still missing, like physical key definitions for ZMK studio. And I only tested with WeAct board. Plus the whole wired split support is still experimental from ZMK side, but I haven't run into any problems yet.

I guess this issue asks to add official ZMK support, but feel free to use anything I added in that module if you want.

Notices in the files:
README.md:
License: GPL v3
